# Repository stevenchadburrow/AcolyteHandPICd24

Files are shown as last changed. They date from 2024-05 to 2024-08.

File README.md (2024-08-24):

<b>Acolyte Hand PIC'd 24</b>

This is a single-chip retro-style computer using only the PIC24EP512GP204 microcontroller.  Inspired by Voja Antonic's design found here:  http://www.voja.rs/PROJECTS/GAME_HTM/1_intro.htm

It is designed to output VGA display at 320x240 with 16 colors, and 2-voice audio square waves.

It is designed to receive input from a Sega Genesis controller, PS/2 Keyboard or Mouse, and 8 on-board buttons.

It is designed to use a MicroSD Card Adapter, and an FT232RL USB Adapter.

Programmed using MPLAB IDE X via a PICkit3.

See my Youtube video for the Bad Apple demo. Either <a href="https://www.youtube.com/watch?v=rc4UsAqcSHg">without audio</a> or <a href="https://youtu.be/sSq6TWw3NXU">with audio</a>.

Also see my 'Pokemon Clone', video link <a href="https://youtu.be/8EHRpKk9gPc">here</a>.  Although I am using the Tuxemon game art assets, this project is not the Tuxemon game, nor are the creators of the Tuxemon game in charge of this project.  This project was simply inspired by the Tuxemon game.

Needed Changes:

*** LED silkscreen is confusing!!! ***

*** ICSP pins physically block the SDcard and FT232RL adapters!!! ***

*** Connected an MCP2221 to the USB connector for serial data transfer!!! ***

*** Tested with LCD, speaker, and with additional PIC24 chip for USB capability!!! ***

Updates:

Been working with the PIC24FJ128GB202 for USB capability.  Using the MLA projects from Microchip, I was able to combine USB Host capabilities for using Keyboad, Mouse, and Mass Storage Device.  See my .ZIP file for the entire project and all associated code.  It is connected to this main board through an RX/TX UART pair, currently at 9600 baud.  

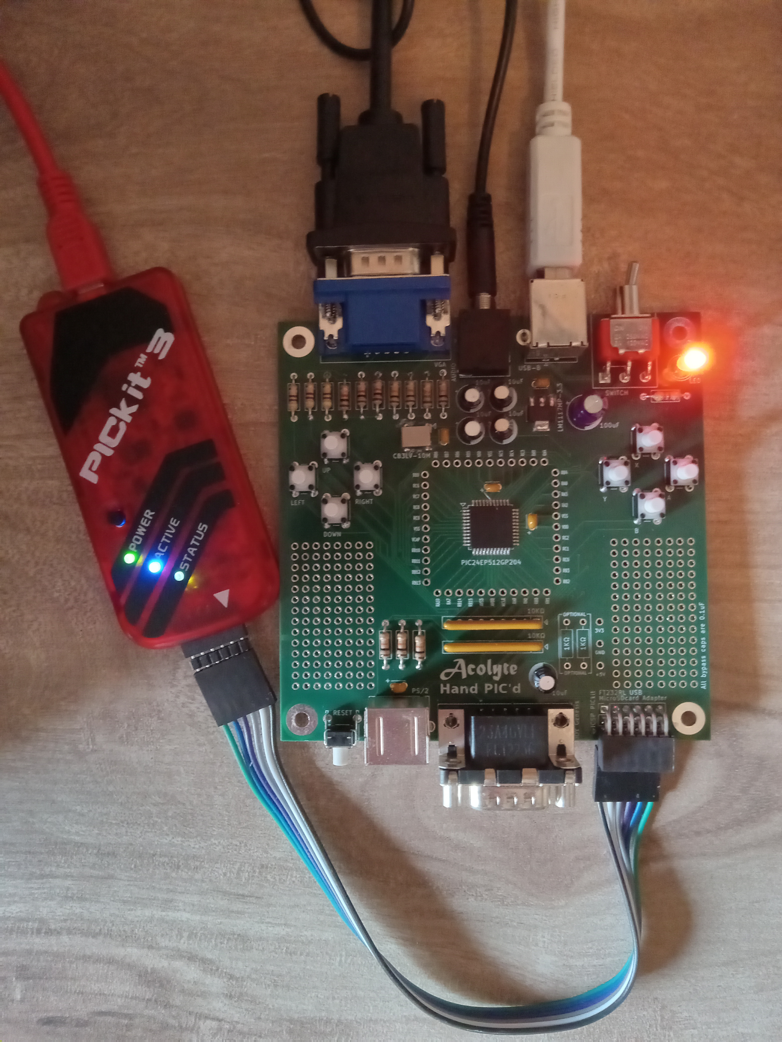
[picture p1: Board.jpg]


A full 16-colors are available!



Tetra always seems to be the first game for any system.

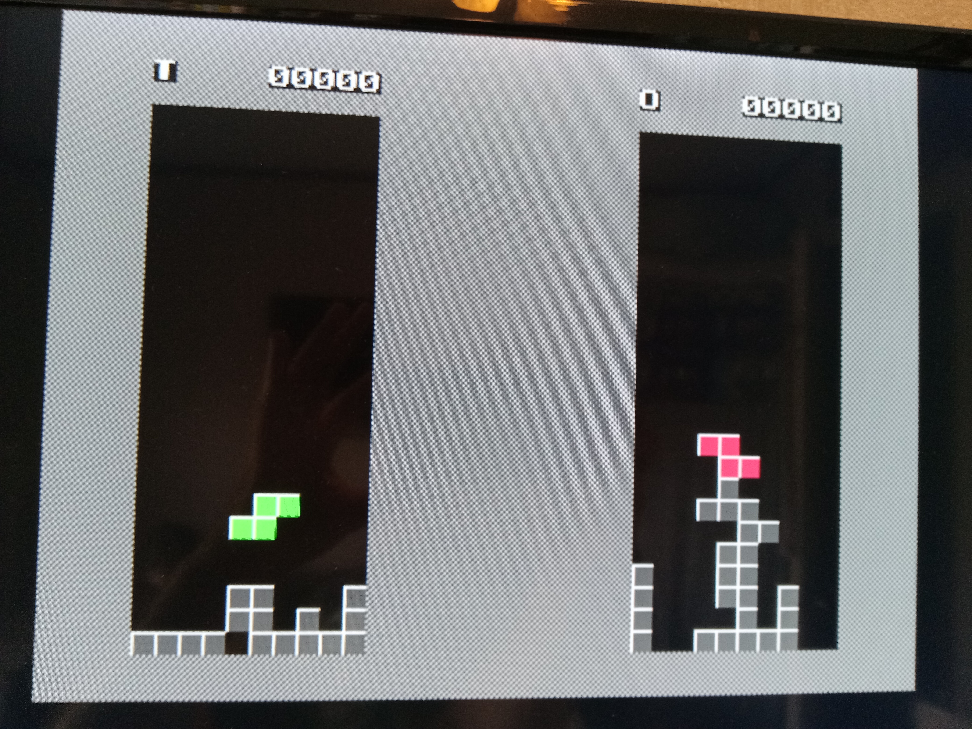
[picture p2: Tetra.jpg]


It can even run Bad Apple!

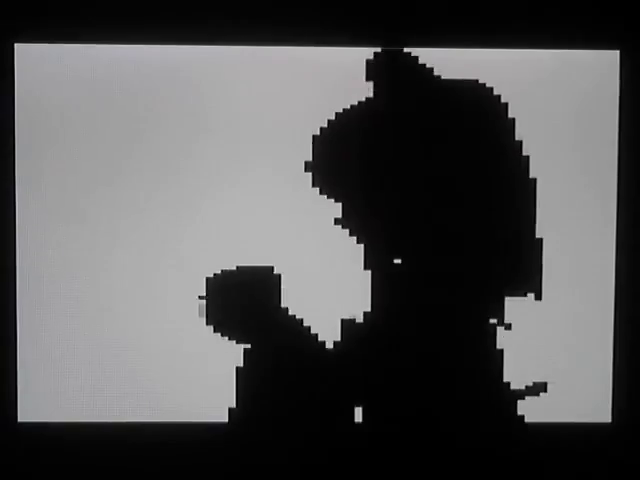
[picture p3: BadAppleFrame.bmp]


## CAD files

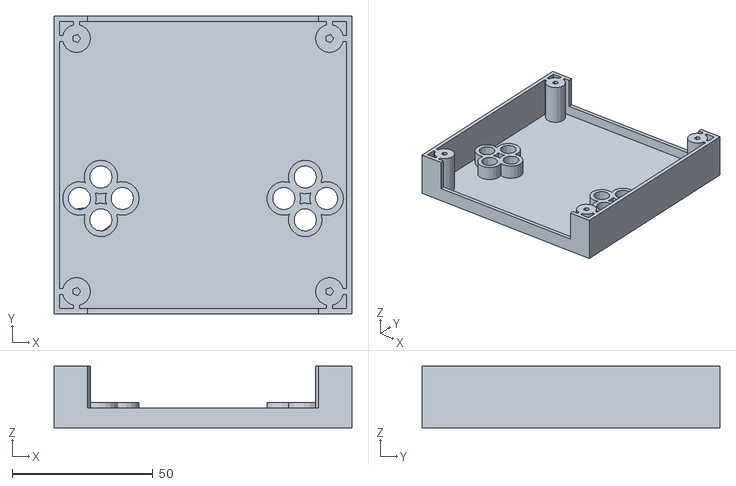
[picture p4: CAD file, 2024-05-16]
HandPICd24-BoxTop.stl
106.0 x 106.0 x 22.0

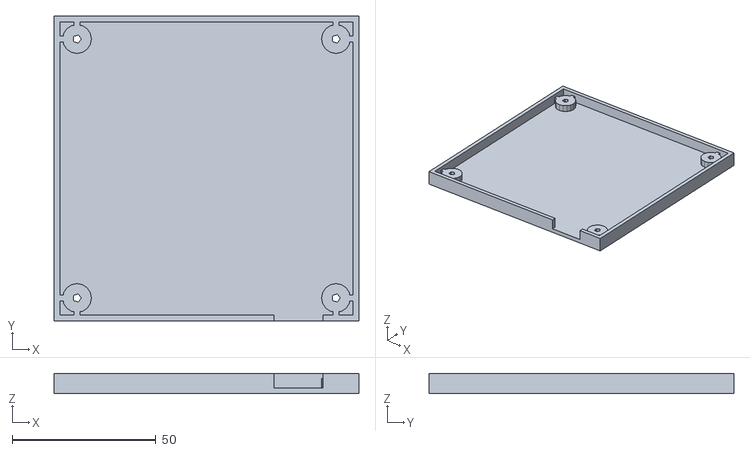
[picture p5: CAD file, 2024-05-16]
HandPICd24-BoxBottom.stl
106.0 x 106.0 x 7.00

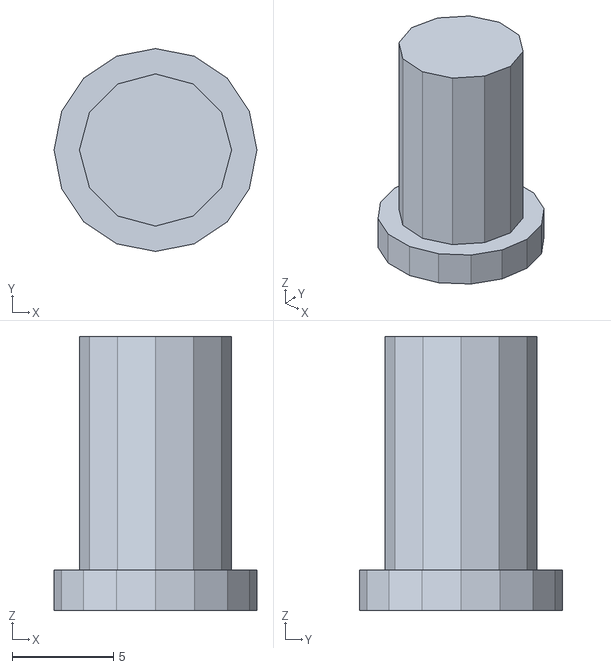
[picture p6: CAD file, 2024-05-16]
HandPICd24-BoxButton.stl
10.0 x 10.0 x 13.5

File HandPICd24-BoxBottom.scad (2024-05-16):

// bottom
translate([-3, -3, -2]) {
    difference() {
        cube([106, 106, 2], center = false);
        translate([3+5, 3+5, -1]) {
            cylinder(4, 3, 3);
        }
        translate([3+95, 3+5, -1]) {
            cylinder(4, 3, 3);
        }
        translate([3+95, 3+95, -1]) {
            cylinder(4, 3, 3);
        }
        translate([3+5, 3+95, -1]) {
            cylinder(4, 3, 3);
        }
    }
}

// front
translate([-3, -3, 0]) {
    difference() {
        cube([106, 2, 5], center = false);
        translate([73.5+3, -0.5, 0]) {
            cube([17, 3, 6], center = false);
        }
    }
}

// back
translate([-3, 101, 0]) {
    cube([106, 2, 5], center = false);
}

// left
translate([-3, -3, 0]) {
    cube([2, 106, 5], center = false);
}

// right
translate([101, -3, 0]) {
    cube([2, 106, 5], center = false);
}

// front left corner
translate([5, 5, 0]) {
    difference() {
        cylinder(3.25, 5, 5);
        translate([0, 0, -1]) {
            cylinder(4.5, 1.5, 1.5);
        }
    }
}
translate([4, -1, 0]) {
    cube([2, 3, 3.25], center = false);
}
translate([-1, 4, 0]) {
    cube([3, 2, 3.25], center = false);
}

// front right corner
translate([95, 5, 0]) {
    difference() {
        cylinder(3.25, 5, 5);
        translate([0, 0, -1]) {
            cylinder(4.5, 1.5, 1.5);
        }
    }
}
translate([94, -1, 0]) {
    cube([2, 3, 3.25], center = false);
}
translate([99, 4, 0]) {
    cube([3, 2, 3.25], center = false);
}

// back right corner
translate([95, 95, 0]) {
    difference() {
        cylinder(3.25, 5, 5);
        translate([0, 0, -1]) {
            cylinder(4.5, 1.5, 1.5);
        }
    }
}
translate([94, 99, 0]) {
    cube([2, 3, 3.25], center = false);
}
translate([99, 94, 0]) {
    cube([3, 2, 3.25], center = false);
}

// back left corner
translate([5, 95, 0]) {
    difference() {
        cylinder(3.25, 5, 5);
        translate([0, 0, -1]) {
            cylinder(4.5, 1.5, 1.5);
        }
    }
}
translate([4, 99, 0]) {
    cube([2, 3, 3.25], center = false);
}
translate([-1, 94, 0]) {
    cube([3, 2, 3.25], center = false);
}


/*
// CSG.scad - Basic example of CSG usage

translate([-24,0,0]) {
    union() {
        cube(15, center=true);
        sphere(10);
    }
}

intersection() {
    cube(15, center=true);
    sphere(10);
}

translate([24,0,0]) {
    difference() {
        cube(15, center=true);
        sphere(10);
    }
}

echo(version=version());
// Written by Marius Kintel <marius@kintel.net>
//
// To the extent possible under law, the author(s) have dedicated all
// copyright and related and neighboring rights to this software to the
// public domain worldwide. This software is distributed without any
// warranty.
//
// You should have received a copy of the CC0 Public Domain
// Dedication along with this software.
// If not, see <http://creativecommons.org/publicdomain/zero/1.0/>.
*/

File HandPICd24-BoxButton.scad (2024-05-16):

difference() {
    cylinder(2, 5, 5);
    cylinder(9, 1.5, 1.5);
}
translate([0, 0, 2]) {
    difference() {
        cylinder(7+2+2.5, 3.75, 3.75);
        cylinder(9, 1.5, 1.5);
    }
}

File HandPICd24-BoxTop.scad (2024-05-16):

// top
translate([-3, -3, -2]) {
    difference() {
        cube([106, 106, 2], center = false);
        
        translate([3, 3, 0]) {
            translate([6.06, 38.1, -1]) {
                cylinder(4, 4, 4);
            }
            translate([13.68, 45.72, -1]) {
                cylinder(4, 4, 4);
            }
            translate([21.3, 38.1, -1]) {
                cylinder(4, 4, 4);
            }
            translate([13.68, 30.48, -1]) {
                cylinder(4, 4, 4);
            }
            
            translate([6.06+72.68, 38.1, -1]) {
                cylinder(4, 4, 4);
            }
            translate([13.68+72.68, 45.72, -1]) {
                cylinder(4, 4, 4);
            }
            translate([21.3+72.68, 38.1, -1]) {
                cylinder(4, 4, 4);
            }
            translate([13.68+72.68, 30.48, -1]) {
                cylinder(4, 4, 4);
            }
        }
    }
}

// buttons
translate([6.06, 38.1, 0]) {
    difference() {
        cylinder(7, 6, 6);
        cylinder(7, 4, 4);
    }
/*
// testing buttons
translate([0, 0, 7]) {
rotate([180, 0, 0]) {
translate([0, 0, -2]) {
// insert button here
difference() {
    cylinder(2, 5, 5);
    cylinder(9, 1.5, 1.5);
}
translate([0, 0, 2]) {
    difference() {
        cylinder(7+2+2.5, 3.75, 3.75);
        cylinder(9, 1.5, 1.5);
    }
}
// end of button
}}}
*/
}
translate([13.68, 45.72, 0]) {
    difference() {
        cylinder(7, 6, 6);
        cylinder(7, 4, 4);
    }
/*    
// testing buttons
translate([0, 0, 7]) {
rotate([180, 0, 0]) {
translate([0, 0, -2]) {
// insert button here
difference() {
    cylinder(2, 5, 5);
    cylinder(9, 1.5, 1.5);
}
translate([0, 0, 2]) {
    difference() {
        cylinder(7+2+2.5, 3.75, 3.75);
        cylinder(9, 1.5, 1.5);
    }
}
// end of button
}}}
*/
}
translate([21.3, 38.1, 0]) {
    difference() {
        cylinder(7, 6, 6);
        cylinder(7, 4, 4);
    }
/*   
// testing buttons
translate([0, 0, 7]) {
rotate([180, 0, 0]) {
translate([0, 0, -2]) {
// insert button here
difference() {
    cylinder(2, 5, 5);
    cylinder(9, 1.5, 1.5);
}
translate([0, 0, 2]) {
    difference() {
        cylinder(7+2+2.5, 3.75, 3.75);
        cylinder(9, 1.5, 1.5);
    }
}
// end of button
}}}
*/    
}
translate([13.68, 30.48, 0]) {
    difference() {
        cylinder(7, 6, 6);
        cylinder(7, 4, 4);
    }
/*    
// testing buttons
translate([0, 0, 7]) {
rotate([180, 0, 0]) {
translate([0, 0, -2]) {
// insert button here
difference() {
    cylinder(2, 5, 5);
    cylinder(9, 1.5, 1.5);
}
translate([0, 0, 2]) {
    difference() {
        cylinder(7+2+2.5, 3.75, 3.75);
        cylinder(9, 1.5, 1.5);
    }
}
// end of button
}}}
*/
}

translate([6.06+72.68, 38.1, 0]) {
    difference() {
        cylinder(7, 6, 6);
        cylinder(7, 4, 4);
    }
}
translate([13.68+72.68, 45.72, 0]) {
    difference() {
        cylinder(7, 6, 6);
        cylinder(7, 4, 4);
    }
}
translate([21.3+72.68, 38.1, 0]) {
    difference() {
        cylinder(7, 6, 6);
        cylinder(7, 4, 4);
    }
}
translate([13.68+72.68, 30.48, 0]) {
    difference() {
        cylinder(7, 6, 6);
        cylinder(7, 4, 4);
    }
}

// back
translate([-3, -3, 0]) {
    difference() {
        cube([106, 2, 20], center = false);
        translate([3+9, -1, 5]) {
            cube([82, 4, 16], center = false);
        }
    }
}

// front
translate([-3, 101, 0]) {
    difference() {
        cube([106, 2, 20], center = false);
        translate([3+9, -1, 5]) {
            cube([82, 4, 16], center = false);
        }
    }
}

// right
translate([-3, -3, 0]) {
    cube([2, 106, 20], center = false);
}

// left
translate([101, -3, 0]) {
    cube([2, 106, 20], center = false);
}

// corner
translate([5, 5, 0]) {
    difference() {
        cylinder(20, 5, 5);
        translate([0, 0, -1]) {
            cylinder(21.25, 1.5, 1.5);
        }
    }
}
translate([4, -1, 0]) {
    cube([2, 3, 20], center = false);
}
translate([-1, 4, 0]) {
    cube([3, 2, 20], center = false);
}

// corner
translate([95, 5, 0]) {
    difference() {
        cylinder(20, 5, 5);
        translate([0, 0, -1]) {
            cylinder(21.25, 1.5, 1.5);
        }
    }
}
translate([94, -1, 0]) {
    cube([2, 3, 20], center = false);
}
translate([99, 4, 0]) {
    cube([3, 2, 20], center = false);
}

// corner
translate([95, 95, 0]) {
    difference() {
        cylinder(20, 5, 5);
        translate([0, 0, -1]) {
            cylinder(21.25, 1.5, 1.5);
        }
    }
}
translate([94, 99, 0]) {
    cube([2, 3, 20], center = false);
}
translate([99, 94, 0]) {
    cube([3, 2, 20], center = false);
}

// corner
translate([5, 95, 0]) {
    difference() {
        cylinder(20, 5, 5);
        translate([0, 0, -1]) {
            cylinder(21.25, 1.5, 1.5);
        }
    }
}
translate([4, 99, 0]) {
    cube([2, 3, 20], center = false);
}
translate([-1, 94, 0]) {
    cube([3, 2, 20], center = false);
}


/*
// CSG.scad - Basic example of CSG usage

translate([-24,0,0]) {
    union() {
        cube(15, center=true);
        sphere(10);
    }
}

intersection() {
    cube(15, center=true);
    sphere(10);
}

translate([24,0,0]) {
    difference() {
        cube(15, center=true);
        sphere(10);
    }
}

echo(version=version());
// Written by Marius Kintel <marius@kintel.net>
//
// To the extent possible under law, the author(s) have dedicated all
// copyright and related and neighboring rights to this software to the
// public domain worldwide. This software is distributed without any
// warranty.
//
// You should have received a copy of the CC0 Public Domain
// Dedication along with this software.
// If not, see <http://creativecommons.org/publicdomain/zero/1.0/>.
*/

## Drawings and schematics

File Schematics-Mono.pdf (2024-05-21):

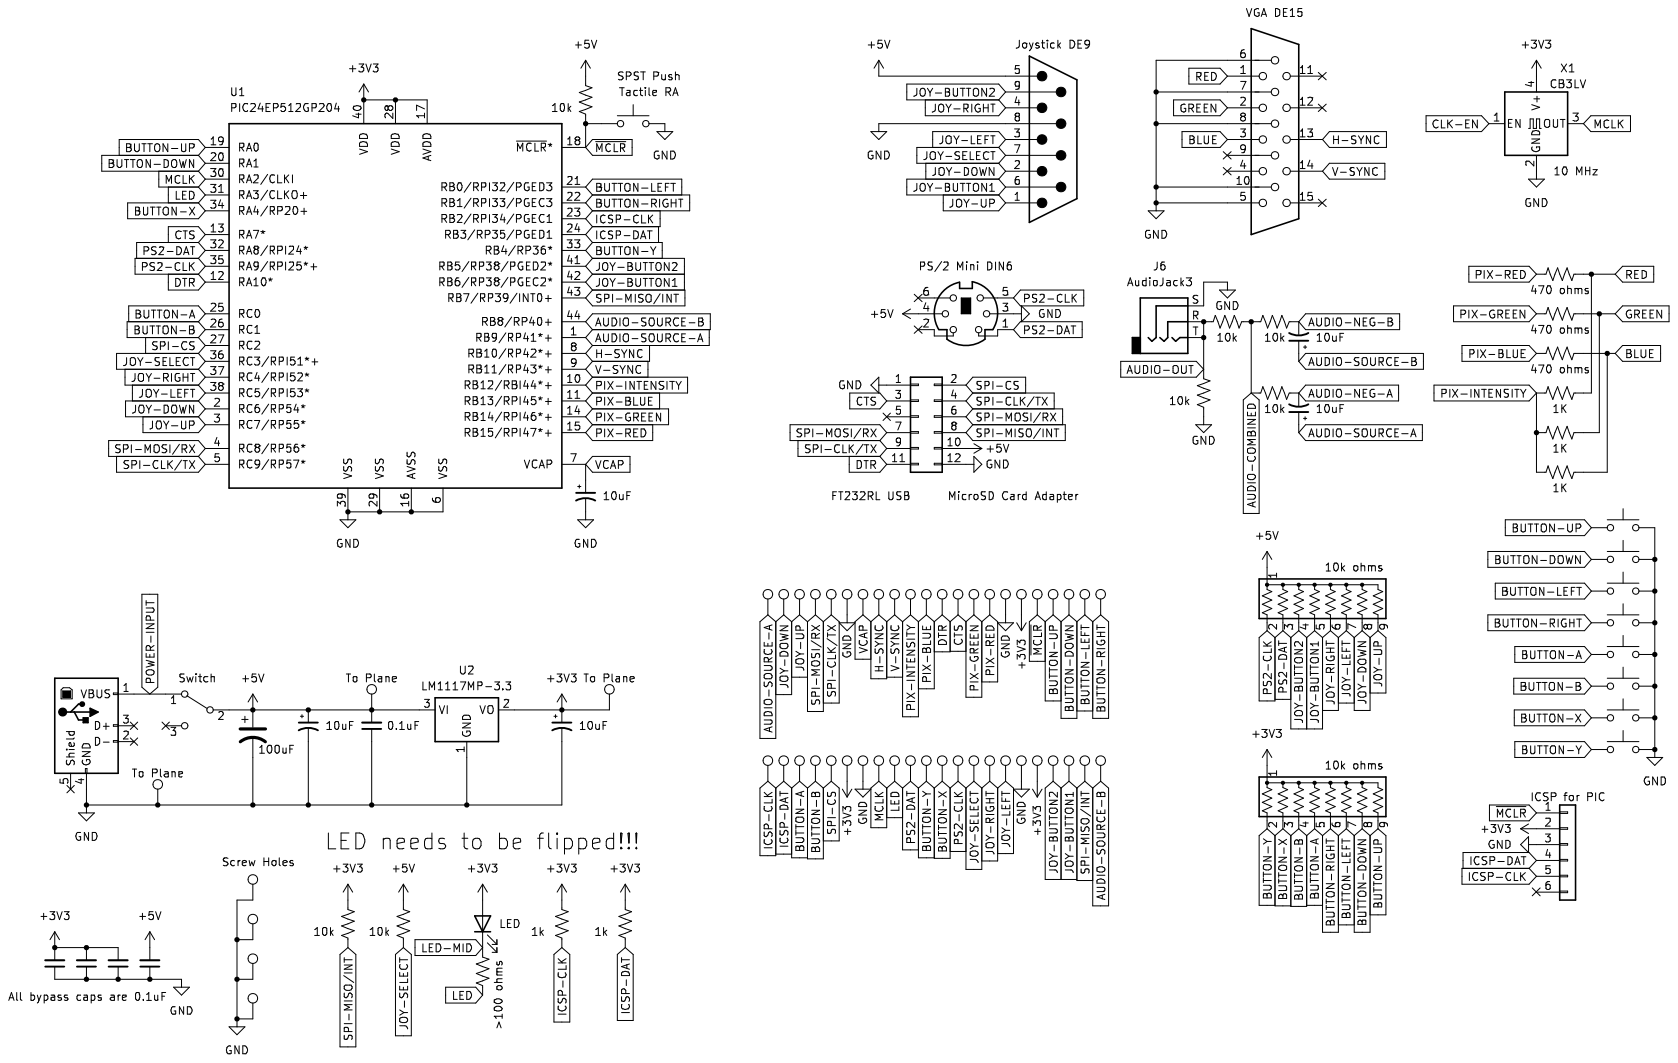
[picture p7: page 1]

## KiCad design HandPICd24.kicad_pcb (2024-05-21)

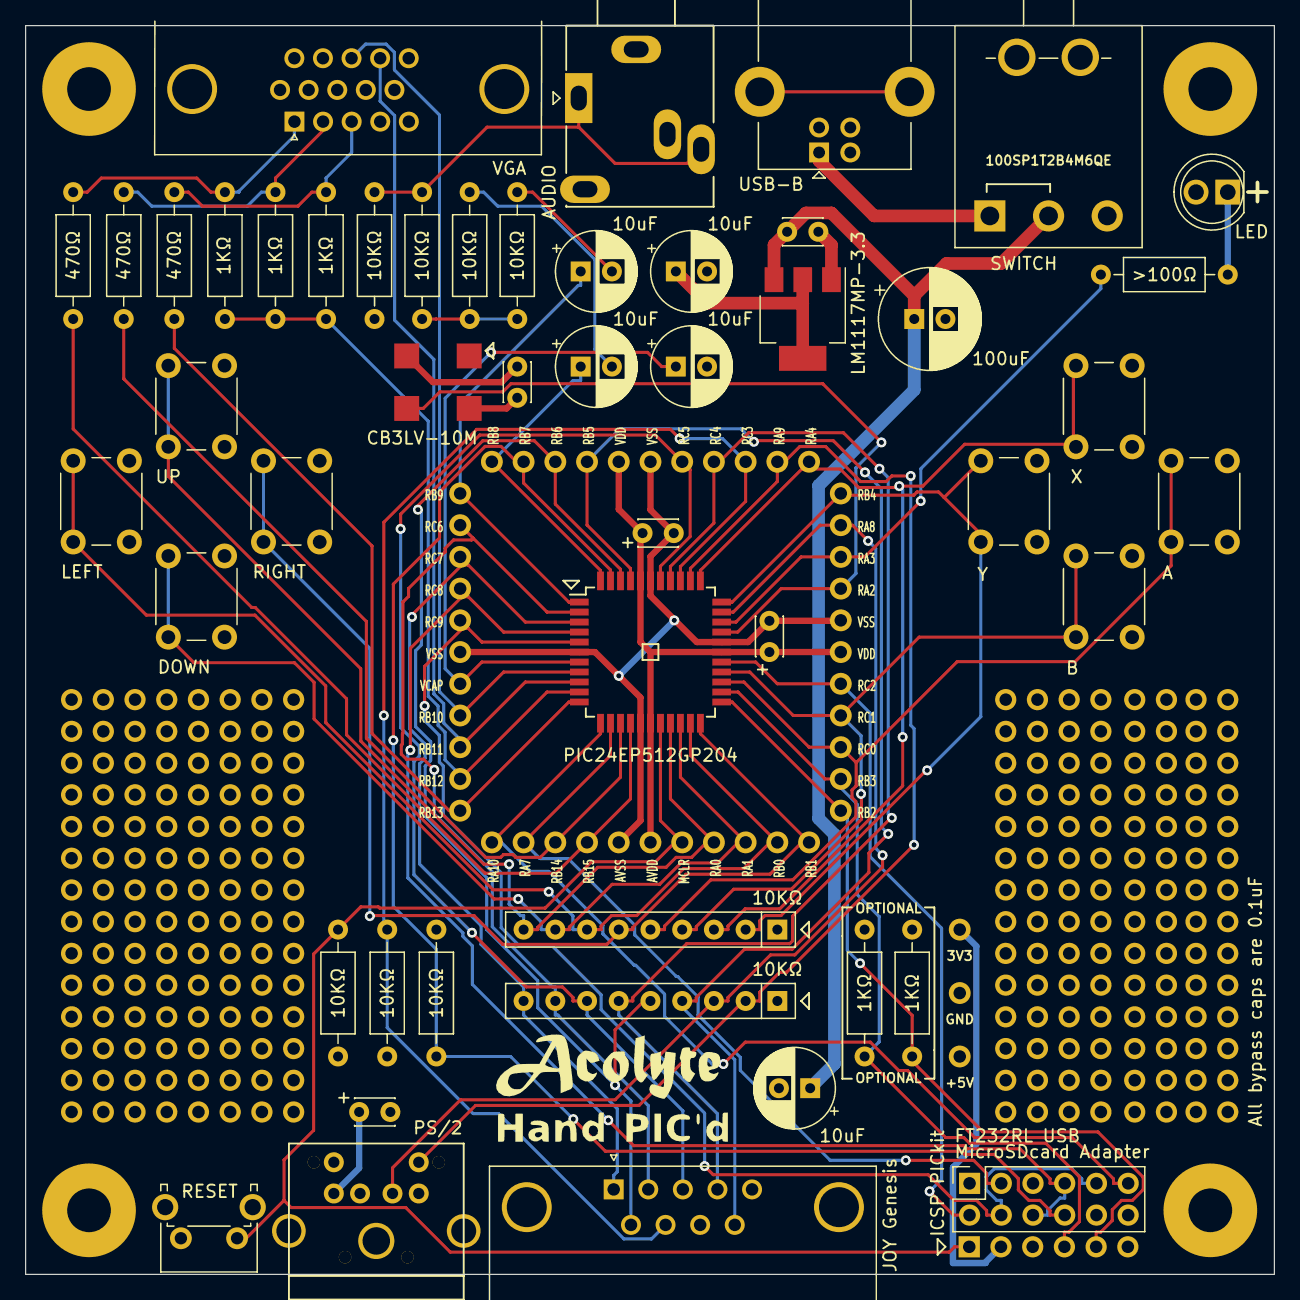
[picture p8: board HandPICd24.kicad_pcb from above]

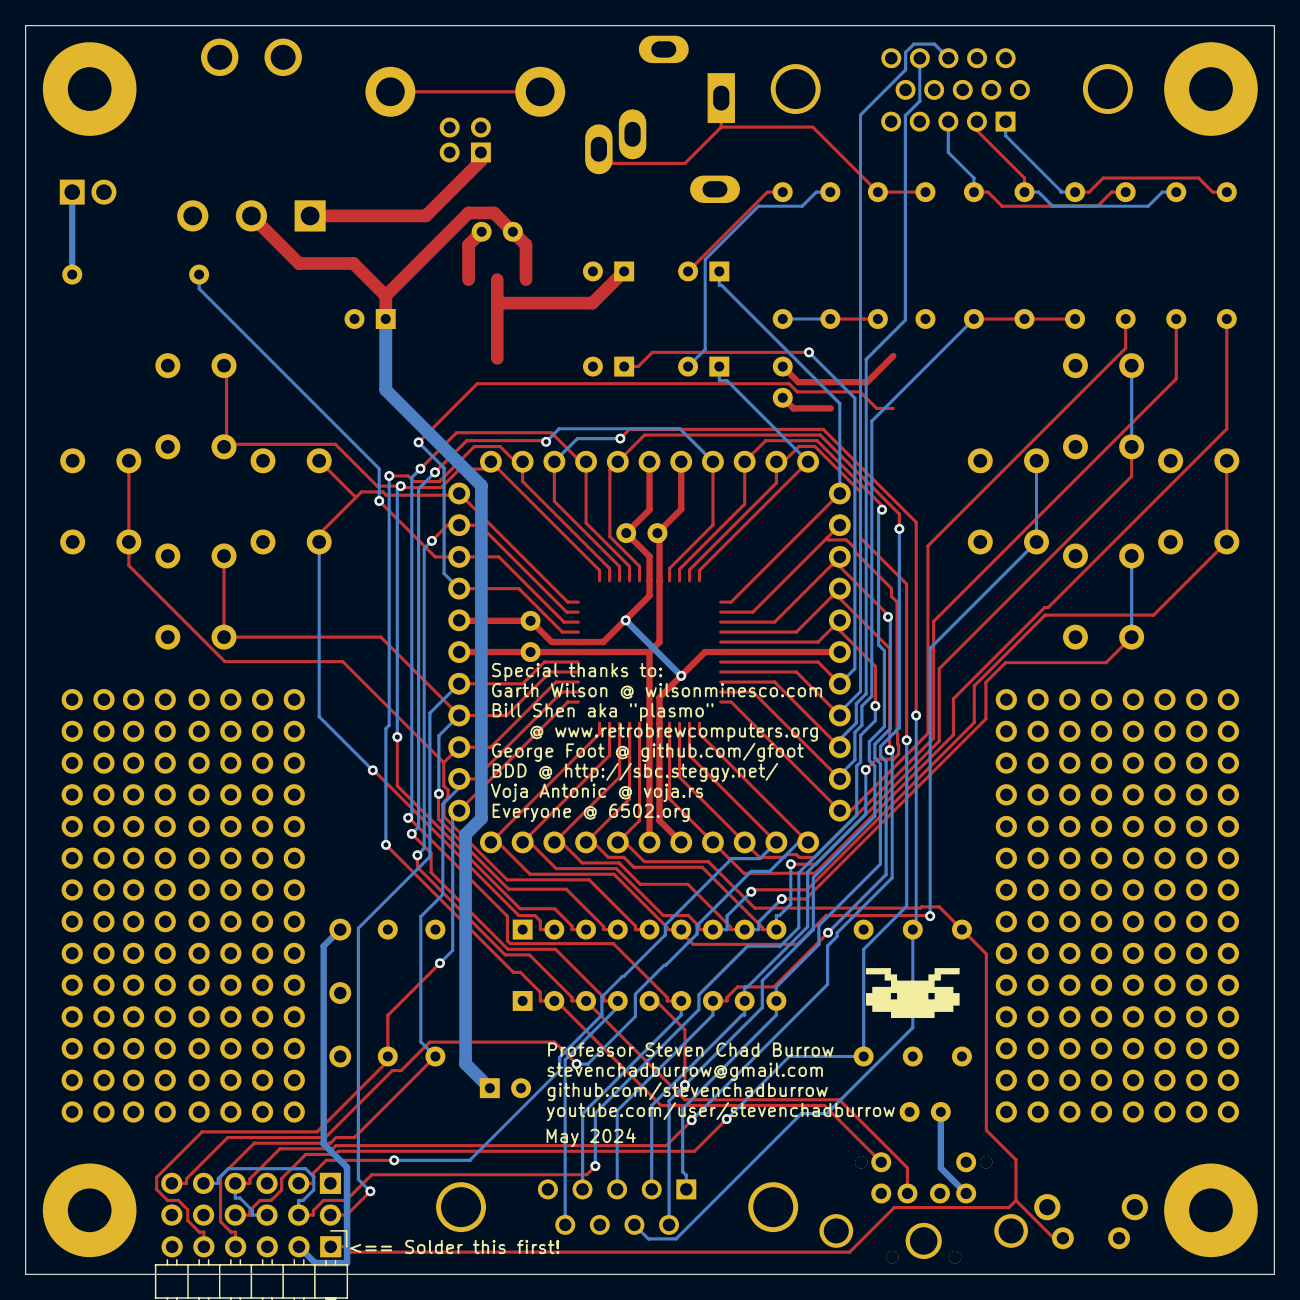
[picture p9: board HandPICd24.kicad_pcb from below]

Board: 4 copper layers, 100.0 x 100.0 mm, 112 parts (2 on the bottom side), 49 nets.

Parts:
C1, C3, C4, C6, C8: C_Polarized_Small_US; CP_Radial_D6.3mm_P2.50mm
C2: C_Polarized_US; CP_Radial_D8.0mm_P2.50mm
C5, C7, C19, C25, C28: C_Small; C_Disc_D3.0mm_W2.0mm_P2.50mm
D1: LED; CustomLED
G101: LOGO; AcolyteTitle
G102: LOGO; HandPickedTitle
G103: LOGO; Mystery
J1: Conn_02x06_Odd_Even; PinSocket_2x06_P2.54mm_Vertical
J2: Mini-DIN-6; PS2_Din6
J3: DE9_Plug; DSUB-9_Male_Horizontal_P2.77x2.84mm_EdgePinOffset7.70mm_Hou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
J4: USB_B; USB_B_Lumberg_2411_02_Horizontal
J5: DE15_Receptacle_HighDensity; DSUB-15-HD_Female_Horizontal_P2.29x2.54mm_VGA
J6: AudioJack3; BIGJack_3.5mm_Ledino_KB3SPRS_Horizontal
J10, J11, J12, J13, J14, J15, J16, J17: Conn_02x14_Odd_Even; BLANK-PinHeader_2x14_P2.54mm_Vertical
J18: Conn_01x06; PinHeader_1x06_P2.54mm_Horizontal
R1, R2, R3, R4, R5, R6, R7, R8, R9, R10, R11, R12, R13, R14, R15, R17: R_US; R_Axial_DIN0207_L6.3mm_D2.5mm_P10.16mm_Horizontal
RN1, RN2: R_Network08_US; R_Array_SIP9
SW1: SW_Push; SW_Tactile_SPST_Angled_PTS645Vx83-2LFS
SW2, SW4, SW5, SW6, SW7, SW8, SW9, SW10: SW_Push; SW_PUSH_6mm_H5mm
SW3: SW_SPDT; SPDT-100SP1T2B4M6QE
TP1, TP2, TP3, TP4: TestPoint; ScrewHole-4-40
TP5, TP6, TP7, TP8, TP9, TP10, TP11, TP12, TP13, TP14, TP15, TP16, TP17, TP18, TP19, TP20, TP21, TP22, TP23, TP24, TP25, TP26, TP27, TP28, TP29, TP30, TP31, TP32, TP33, TP34, TP35, TP36, TP37, TP38, TP39, TP40, TP41, TP42, TP43, TP44, TP45, TP46, TP47, TP48, TP49, TP50, TP53: TestPoint; TestPointStdTHT
U1: PIC24EP512GP204; TQFP-44_10x10mm_P0.8mm
U2: LM1117MP-3.3; SOT-223-3_TabPin2
X1: CB3LV; Oscillator_SMD_EuroQuartz_XO91-4Pin_7.0x5.0mm

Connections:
+3V3: C6.1, C19.2, C25.2, C28.2, D1.2 (A), J18.2, R4.2, R7.2, R15.2, RN2.1 (common), TP21.1, TP32.1, TP44.1, TP53.1, U1.17 (AVDD), U1.28 (VDD), U1.40 (VDD), U2.2 (VO), X1.4 (V+)
+5V: C2.1, C5.2, C7.2, C8.1, J1.10, J2.4, J3.5, R1.2, R17.2, RN1.1 (common), SW3.2 (B), TP50.1, U2.3 (VI)
AUDIO-COMBINED: R3.2, R5.1, R6.1
AUDIO-NEG-A: C4.2, R6.2
AUDIO-NEG-B: C3.2, R5.2
AUDIO-OUT: J6.R, J6.T, R2.2, R3.1
AUDIO-SOURCE-A: C4.1, TP5.1, U1.1 (RB9/RP41*+)
AUDIO-SOURCE-B: C3.1, TP48.1, U1.44 (RB8/RP40+)
BLUE: J5.3, R10.2, R13.2
BUTTON-A: RN2.5 (R4), SW7.1, TP29.1, U1.25 (RC0)
BUTTON-B: RN2.4 (R3), SW8.1, TP30.1, U1.26 (RC1)
BUTTON-DOWN: RN2.8 (R7), SW4.1, TP24.1, U1.20 (RA1)
BUTTON-LEFT: RN2.7 (R6), SW5.1, TP25.1, U1.21 (RB0/RPI32/PGED3)
BUTTON-RIGHT: RN2.6 (R5), SW6.1, TP26.1, U1.22 (RB1/RPI33/PGEC3)
BUTTON-UP: RN2.9 (R8), SW2.1, TP23.1, U1.19 (RA0)
BUTTON-X: RN2.3 (R2), SW9.1, TP38.1, U1.34 (RA4/RP20+)
BUTTON-Y: RN2.2 (R1), SW10.1, TP37.1, U1.33 (RB4/RP36*)
CTS: J1.3, TP17.1, U1.13 (RA7*)
DTR: J1.11, TP16.1, U1.12 (RA10*)
GND: C1.2, C2.2, C5.1, C6.2, C7.1, C8.2, C19.1, C25.1, C28.1, J1.1, J1.12, J2.3, J3.8, J4.4 (GND), J5.5, J5.6, J5.7, J5.8, J5.10, J6.S, J18.3, R2.1, SW1.2, SW2.2, SW4.2, SW5.2, SW6.2, SW7.2, SW8.2, SW9.2, SW10.2, TP1.1, TP2.1, TP3.1, TP4.1, TP10.1, TP20.1, TP33.1, TP43.1, TP49.1, U1.6 (VSS), U1.16 (AVSS), U1.29 (VSS), U1.39 (VSS), U2.1 (GND), X1.2 (GND)
GREEN: J5.2, R9.2, R12.2
H-SYNC: J5.13, TP12.1, U1.8 (RB10/RP42*+)
ICSP-CLK: J18.5, R4.1, TP27.1, U1.23 (RB2/RPI34/PGEC1)
ICSP-DAT: J18.4, R15.1, TP28.1, U1.24 (RB3/RP35/PGED1)
JOY-BUTTON1: J3.6, RN1.5 (R4), TP46.1, U1.42 (RB6/RP38/PGEC2*)
JOY-BUTTON2: J3.9, RN1.4 (R3), TP45.1, U1.41 (RB5/RP38/PGED2*)
JOY-DOWN: J3.2, RN1.8 (R7), TP6.1, U1.2 (RC6/RP54*)
JOY-LEFT: J3.3, RN1.7 (R6), TP42.1, U1.38 (RC5/RPI53*)
JOY-RIGHT: J3.4, RN1.6 (R5), TP41.1, U1.37 (RC4/RPI52*)
JOY-SELECT: J3.7, R17.1, TP40.1, U1.36 (RC3/RPI51*+)
JOY-UP: J3.1, RN1.9 (R8), TP7.1, U1.3 (RC7/RP55*)
LED: R14.2, TP35.1, U1.31 (RA3/CLKO+)
LED-MID: D1.1 (K), R14.1
MCLK: TP34.1, U1.30 (RA2/CLKI), X1.3 (OUT)
PIX-BLUE: R10.1, TP15.1, U1.11 (RB13/RPI45*+)
PIX-GREEN: R9.1, TP18.1, U1.14 (RB14/RPI46*+)
PIX-INTENSITY: R11.1, R12.1, R13.1, TP14.1, U1.10 (RB12/RBI44*+)
PIX-RED: R8.1, TP19.1, U1.15 (RB15/RPI47*+)
POWER-INPUT: J4.1 (VBUS), SW3.1 (A)
PS2-CLK: J2.5, RN1.2 (R1), TP39.1, U1.35 (RA9/RPI25*+)
PS2-DAT: J2.1, RN1.3 (R2), TP36.1, U1.32 (RA8/RPI24*)
RED: J5.1, R8.2, R11.2
SPI-CLK/TX: J1.4, J1.9, TP9.1, U1.5 (RC9/RP57*)
SPI-CS: J1.2, TP31.1, U1.27 (RC2)
SPI-MISO/INT: J1.8, R7.1, TP47.1, U1.43 (RB7/RP39/INT0+)
SPI-MOSI/RX: J1.6, J1.7, TP8.1, U1.4 (RC8/RP56*)
V-SYNC: J5.14, TP13.1, U1.9 (RB11/RP43*+)
VCAP: C1.1, TP11.1, U1.7 (VCAP)
~MCLR: J18.1, R1.1, SW1.1, TP22.1, U1.18 (~MCLR*)

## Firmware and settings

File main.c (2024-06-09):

/******************************************************************************/
/* Files to Include                                                           */
/******************************************************************************/

/* Device header file */
#if defined(__XC16__)
    #include <xc.h>
#elif defined(__C30__)
    #if defined(__PIC24E__)
    	#include <p24Exxxx.h>
    #elif defined (__PIC24F__)||defined (__PIC24FK__)
	#include <p24Fxxxx.h>
    #elif defined(__PIC24H__)
	#include <p24Hxxxx.h>
    #endif
#endif

#include <stdint.h>        /* Includes uint16_t definition                    */
#include <stdbool.h>       /* Includes true/false definition                  */

/* Microcontroller MIPs (FCY) */
#define SYS_FREQ        10000000L
#define FCY             SYS_FREQ/2


/*
// PIC24EP512GP204 Configuration Bit Settings

// 'C' source line config statements

// FICD
#pragma config ICS = PGD1               // ICD Communication Channel Select bits (Communicate on PGEC1 and PGED1)
#pragma config JTAGEN = OFF             // JTAG Enable bit (JTAG is disabled)

// FPOR
#pragma config ALTI2C1 = OFF            // Alternate I2C1 pins (I2C1 mapped to SDA1/SCL1 pins)
#pragma config ALTI2C2 = OFF            // Alternate I2C2 pins (I2C2 mapped to SDA2/SCL2 pins)
#pragma config WDTWIN = WIN25           // Watchdog Window Select bits (WDT Window is 25% of WDT period)

// FWDT
#pragma config WDTPOST = PS32768        // Watchdog Timer Postscaler bits (1:32,768)
#pragma config WDTPRE = PR128           // Watchdog Timer Prescaler bit (1:128)
#pragma config PLLKEN = ON              // PLL Lock Enable bit (Clock switch to PLL source will wait until the PLL lock signal is valid.)
#pragma config WINDIS = OFF             // Watchdog Timer Window Enable bit (Watchdog Timer in Non-Window mode)
#pragma config FWDTEN = OFF             // Watchdog Timer Enable bit (Watchdog timer enabled/disabled by user software)

// FOSC
#pragma config POSCMD = EC              // Primary Oscillator Mode Select bits (EC (External Clock) Mode)
#pragma config OSCIOFNC = ON            // OSC2 Pin Function bit (OSC2 is general purpose digital I/O pin)
#pragma config IOL1WAY = OFF            // Peripheral pin select configuration (Allow multiple reconfigurations)
#pragma config FCKSM = CSECMD           // Clock Switching Mode bits (Clock switching is enabled,Fail-safe Clock Monitor is disabled)

// FOSCSEL
#pragma config FNOSC = FRC              // Oscillator Source Selection (Internal Fast RC (FRC))
#pragma config IESO = OFF               // Two-speed Oscillator Start-up Enable bit (Start up with user-selected oscillator source)

// FGS
#pragma config GWRP = OFF               // General Segment Write-Protect bit (General Segment may be written)
#pragma config GCP = OFF                // General Segment Code-Protect bit (General Segment Code protect is Disabled)

// #pragma config statements should precede project file includes.
// Use project enums instead of #define for ON and OFF.

#include <xc.h>
*/



// PIC24EP512GP204 Configuration Bit Settings

// 'C' source line config statements

// FICD
#pragma config ICS = PGD1               // ICD Communication Channel Select bits (Communicate on PGEC1 and PGED1)
#pragma config JTAGEN = OFF             // JTAG Enable bit (JTAG is disabled)

// FPOR
#pragma config ALTI2C1 = OFF            // Alternate I2C1 pins (I2C1 mapped to SDA1/SCL1 pins)
#pragma config ALTI2C2 = OFF            // Alternate I2C2 pins (I2C2 mapped to SDA2/SCL2 pins)
#pragma config WDTWIN = WIN25           // Watchdog Window Select bits (WDT Window is 25% of WDT period)

// FWDT
#pragma config WDTPOST = PS32768        // Watchdog Timer Postscaler bits (1:32,768)
#pragma config WDTPRE = PR128           // Watchdog Timer Prescaler bit (1:128)
#pragma config PLLKEN = ON              // PLL Lock Enable bit (Clock switch to PLL source will wait until the PLL lock signal is valid.)
#pragma config WINDIS = OFF             // Watchdog Timer Window Enable bit (Watchdog Timer in Non-Window mode)
#pragma config FWDTEN = OFF             // Watchdog Timer Enable bit (Watchdog timer enabled/disabled by user software)

// FOSC
#pragma config POSCMD = XT              // Primary Oscillator Mode Select bits (XT Crystal Oscillator Mode)
#pragma config OSCIOFNC = OFF           // OSC2 Pin Function bit (OSC2 is clock output)
#pragma config IOL1WAY = OFF            // Peripheral pin select configuration (Allow multiple reconfigurations)
#pragma config FCKSM = CSECMD           // Clock Switching Mode bits (Clock switching is enabled,Fail-safe Clock Monitor is disabled)

// FOSCSEL
#pragma config FNOSC = PRIPLL           // Oscillator Source Selection (Primary Oscillator with PLL module (XT + PLL, HS + PLL, EC + PLL))
#pragma config IESO = ON                // Two-speed Oscillator Start-up Enable bit (Start up device with FRC, then switch to user-selected oscillator source)

// FGS
#pragma config GWRP = OFF               // General Segment Write-Protect bit (General Segment may be written)
#pragma config GCP = OFF                // General Segment Code-Protect bit (General Segment Code protect is Disabled)

// #pragma config statements should precede project file includes.
// Use project enums instead of #define for ON and OFF.

#include <xc.h>



/******************************************************************************/
/* Trap Function Prototypes                                                   */
/******************************************************************************/

/* <Other function prototypes for debugging trap code may be inserted here>   */

/* Use if INTCON2 ALTIVT=1 */
void __attribute__((interrupt,no_auto_psv)) _OscillatorFail(void);
void __attribute__((interrupt,no_auto_psv)) _AddressError(void);
void __attribute__((interrupt,no_auto_psv)) _StackError(void);
void __attribute__((interrupt,no_auto_psv)) _MathError(void);

#if defined(__PIC24F__)||defined(__PIC24H__)

/* Use if INTCON2 ALTIVT=0 */
void __attribute__((interrupt,no_auto_psv)) _AltOscillatorFail(void);
void __attribute__((interrupt,no_auto_psv)) _AltAddressError(void);
void __attribute__((interrupt,no_auto_psv)) _AltStackError(void);
void __attribute__((interrupt,no_auto_psv)) _AltMathError(void);

#endif

/* Default interrupt handler */
void __attribute__((interrupt,no_auto_psv)) _DefaultInterrupt(void);

#if defined(__PIC24E__)

/* These are additional traps in the 24E family.  Refer to the PIC24E
migration guide.  There are no Alternate Vectors in the 24E family. */
void __attribute__((interrupt,no_auto_psv)) _HardTrapError(void);
void __attribute__((interrupt,no_auto_psv)) _DMACError(void);
void __attribute__((interrupt,no_auto_psv)) _SoftTrapError(void);

#endif

/******************************************************************************/
/* Trap Handling                                                              */
/*                                                                            */
/* These trap routines simply ensure that the device continuously loops       */
/* within each routine.  Users who actually experience one of these traps     */
/* can add code to handle the error.  Some basic examples for trap code,      */
/* including assembly routines that process trap sources, are available at    */
/* www.microchip.com/codeexamples                                             */
/******************************************************************************/

/* Primary (non-alternate) address error trap function declarations */
void __attribute__((interrupt,no_auto_psv)) _OscillatorFail(void)
{
        INTCON1bits.OSCFAIL = 0;        /* Clear the trap flag */
        while(1);
}

void __attribute__((interrupt,no_auto_psv)) _AddressError(void)
{
        INTCON1bits.ADDRERR = 0;        /* Clear the trap flag */
        while (1);
}
void __attribute__((interrupt,no_auto_psv)) _StackError(void)
{
        INTCON1bits.STKERR = 0;         /* Clear the trap flag */
        while (1);
}

void __attribute__((interrupt,no_auto_psv)) _MathError(void)
{
        INTCON1bits.MATHERR = 0;        /* Clear the trap flag */
        while (1);
}

#if defined(__PIC24F__)||defined(__PIC24H__)

/* Alternate address error trap function declarations */
void __attribute__((interrupt,no_auto_psv)) _AltOscillatorFail(void)
{
        INTCON1bits.OSCFAIL = 0;        /* Clear the trap flag */
        while (1);
}

void __attribute__((interrupt,no_auto_psv)) _AltAddressError(void)
{
        INTCON1bits.ADDRERR = 0;        /* Clear the trap flag */
        while (1);
}

void __attribute__((interrupt,no_auto_psv)) _AltStackError(void)
{
        INTCON1bits.STKERR = 0;         /* Clear the trap flag */
        while (1);
}

void __attribute__((interrupt,no_auto_psv)) _AltMathError(void)
{
        INTCON1bits.MATHERR = 0;        /* Clear the trap flag */
        while (1);
}

#endif

/******************************************************************************/
/* Default Interrupt Handler                                                  */
/*                                                                            */
/* This executes when an interrupt occurs for an interrupt source with an     */
/* improperly defined or undefined interrupt handling routine.                */
/******************************************************************************/
void __attribute__((interrupt,no_auto_psv)) _DefaultInterrupt(void)
{
        while(1);
}

#if defined(__PIC24E__)

/* These traps are new to the PIC24E family.  Refer to the device Interrupt
chapter of the FRM to understand trap priority. */
void __attribute__((interrupt,no_auto_psv)) _HardTrapError(void)
{
    while(1);
}
void __attribute__((interrupt,no_auto_psv)) _DMACError(void)
{
    while(1);
}
void __attribute__((interrupt,no_auto_psv)) _SoftTrapError(void)
{
    while(1);
}

#endif

/******************************************************************************/
/* Main Program                                                               */
/******************************************************************************/


// only 80 used, but last 2 needed for other reasons
unsigned int line[96] __at(0x1000) = {
  0x0000, 0x0000, 0x0000, 0x0000,
  0x0000, 0x0000, 0x0000, 0x0000,
  0x0000, 0x0000, 0x0000, 0x0000,
  0x0000, 0x0000, 0x0000, 0x0000,
  
  0x0000, 0x0000, 0x0000, 0x0000,
  0x0000, 0x0000, 0x0000, 0x0000,
  0x0000, 0x0000, 0x0000, 0x0000,
  0x0000, 0x0000, 0x0000, 0x0000,
  
  0x0000, 0x0000, 0x0000, 0x0000,
  0x0000, 0x0000, 0x0000, 0x0000,
  0x0000, 0x0000, 0x0000, 0x0000,
  0x0000, 0x0000, 0x0000, 0x0000,
  
  0x0000, 0x0000, 0x0000, 0x0000,
  0x0000, 0x0000, 0x0000, 0x0000,
  0x0000, 0x0000, 0x0000, 0x0000,
  0x0000, 0x0000, 0x0000, 0x0000,
  
  0x0000, 0x0000, 0x0000, 0x0000,
  0x0000, 0x0000, 0x0000, 0x0000,
  0x0000, 0x0000, 0x0000, 0x0000,
  0x0000, 0x0000, 0x0000, 0x0000,
  
  0x0000, 0x0000, 0x0000, 0x0000,
  0x0000, 0x0000, 0x0000, 0x0000,
  0x0000, 0x0000, 0x0000, 0x0000,
  0x0000, 0x0000, 0x0000, 0x0000
};

// 80 * 240 * 2-byte word = 38400 bytes
// 80 words * 4 pixels per word = 320 pixels horizontal
// 240 pixels vertically
// result: 320x240 with 16 colors
unsigned int screen[80*240] __at(0x2000);

// interrupt latency is 10 cycles
// for some reason, having auto_psv instead of no_auto_psv makes this work?!
void __attribute__((__interrupt__, auto_psv, address(0x002000))) _T1Interrupt(void)
{
	// C always includes:
	// lnk #0
  
	drawScanline();
	
	// C always includes:
	// ulnk
	// retfie
};



const __prog__ unsigned int __attribute__((space(prog))) character_bitmap[1536] = 
//const unsigned int character_bitmap[1536] =
{
	0x0000,0x0000,0x0000,0x0000,0x0000,0x0000,0x0000,0x0000, // 32
	0x0000,0x0000,0x0000,0x0000,0x0000,0x0000,0x0000,0x0000,
	0x00FF,0x0000,0x0FFF,0xF000,0x0FFF,0xF000,0x0FFF,0xF000,
	0x00FF,0x0000,0x0000,0x0000,0x00FF,0x0000,0x0000,0x0000,
	0x00F0,0x0F00,0x0F00,0xF000,0x0FF0,0xFF00,0x0FF0,0xFF00,
	0x0000,0x0000,0x0000,0x0000,0x0000,0x0000,0x0000,0x0000,
	0x0FF0,0xFF00,0xFFFF,0xFFF0,0x0FF0,0xFF00,0x0FF0,0xFF00,
	0x0FF0,0xFF00,0xFFFF,0xFFF0,0x0FF0,0xFF00,0x0000,0x0000,
	0x000F,0x0000,0x0FFF,0xFFF0,0xFF0F,0x0000,0x0FFF,0xFF00,
	0x000F,0x0FF0,0xFFFF,0xFF00,0x000F,0x0000,0x0000,0x0000,
	0x0F00,0x00F0,0xF0F0,0x0FF0,0x0F00,0xFF00,0x000F,0xF000,
	0x00FF,0x0F00,0x0FF0,0xF0F0,0xFF00,0x0F00,0x0000,0x0000,
	0x0FFF,0x0000,0xFF0F,0xF000,0x0FFF,0x0000,0xFF0F,0xF0F0,
	0xFF00,0xFFF0,0xFF00,0x0FF0,0x0FFF,0xFF00,0x0000,0x0000,
	0x00FF,0x0000,0x00FF,0x0000,0x000F,0x0000,0x00F0,0x0000,
	0x0000,0x0000,0x0000,0x0000,0x0000,0x0000,0x0000,0x0000,
	0x000F,0xFF00,0x00FF,0x0000,0x0FF0,0x0000,0x0FF0,0x0000,
	0x0FF0,0x0000,0x00FF,0x0000,0x000F,0xFF00,0x0000,0x0000,
	0x0FFF,0x0000,0x000F,0xF000,0x0000,0xFF00,0x0000,0xFF00,
	0x0000,0xFF00,0x000F,0xF000,0x0FFF,0x0000,0x0000,0x0000,
	0x0000,0x0000,0x0000,0x0000,0x0FF0,0xFF00,0x00FF,0xF000,
	0x0FF0,0xFF00,0x0000,0x0000,0x0000,0x0000,0x0000,0x0000,
	0x0000,0x0000,0x0000,0x0000,0x000F,0x0000,0x000F,0x0000,
	0x0FFF,0xFF00,0x000F,0x0000,0x000F,0x0000,0x0000,0x0000,
	0x0000,0x0000,0x0000,0x0000,0x0000,0x0000,0x00FF,0x0000,
	0x00FF,0x0000,0x000F,0x0000,0x00F0,0x0000,0x0000,0x0000,
	0x0000,0x0000,0x0000,0x0000,0x0000,0x0000,0x0000,0x0000,
	0x0FFF,0xFF00,0x0000,0x0000,0x0000,0x0000,0x0000,0x0000,
	0x0000,0x0000,0x0000,0x0000,0x0000,0x0000,0x0000,0x0000,
	0x0000,0x0000,0x00FF,0x0000,0x00FF,0x0000,0x0000,0x0000,
	0x0000,0x0F00,0x0000,0xFF00,0x000F,0xF000,0x00FF,0x0000,
	0x0FF0,0x0000,0xFF00,0x0000,0xF000,0x0000,0x0000,0x0000,
	0x0FFF,0xFF00,0xFF00,0x0FF0,0xFF00,0xFFF0,0xFF0F,0x0FF0,
	0xFFF0,0x0FF0,0xFF00,0x0FF0,0x0FFF,0xFF00,0x0000,0x0000,
	0xFFFF,0xF000,0x00FF,0xF000,0x00FF,0xF000,0x00FF,0xF000,
	0x00FF,0xF000,0x00FF,0xF000,0xFFFF,0xFFF0,0x0000,0x0000,
	0x0FFF,0xFF00,0xFF00,0x0FF0,0x0000,0xFF00,0x00FF,0xF000,
	0x0FF0,0x0000,0xFF00,0x0000,0xFFFF,0xFFF0,0x0000,0x0000,
	0x0FFF,0xFF00,0xFF00,0x0FF0,0x0000,0x0FF0,0x00FF,0xFF00,
	0x0000,0x0FF0,0xFF00,0x0FF0,0x0FFF,0xFF00,0x0000,0x0000,
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
};

const __prog__ unsigned char __attribute__((space(prog))) character_conversion[256] = 
//const unsigned char character_conversion[256] =
{
  	0x00,0x16,0x0C,0x0E,0x1E,0x1C,0x1D,0x15,
	0x00,0x18,0x07,0x0F,0x1F,0x09,0x60,0x00,
	0x00,0x00,0x00,0x00,0x00,0x71,0x31,0x00,
	0x00,0x00,0x7A,0x73,0x61,0x77,0x32,0x00,
	0x00,0x63,0x78,0x64,0x65,0x34,0x33,0x00,
	0x00,0x20,0x76,0x66,0x74,0x72,0x35,0x00,
	0x00,0x6E,0x62,0x68,0x67,0x79,0x36,0x00,
	0x00,0x00,0x6D,0x6A,0x75,0x37,0x38,0x00,
	0x00,0x2C,0x6B,0x69,0x6F,0x30,0x39,0x00,
	0x00,0x2E,0x2F,0x6C,0x3B,0x70,0x2D,0x00,
	0x00,0x00,0x27,0x00,0x5B,0x3D,0x00,0x00,
	0x00,0x00,0x0D,0x5D,0x00,0x5C,0x00,0x00,
	0x00,0x00,0x00,0x00,0x00,0x00,0x08,0x00,
	0x00,0x31,0x00,0x34,0x37,0x00,0x00,0x00,
	0x30,0x2E,0x32,0x35,0x36,0x38,0x1B,0x00,
	0x19,0x2B,0x33,0x2D,0x2A,0x39,0x00,0x00,

	0x00,0x16,0x0C,0x0E,0x1E,0x1C,0x1D,0x15,
	0x00,0x18,0x07,0x0F,0x1F,0x09,0x7E,0x00,
	0x00,0x00,0x00,0x00,0x00,0x51,0x21,0x00,
	0x00,0x00,0x5A,0x53,0x41,0x57,0x40,0x00,
	0x00,0x43,0x58,0x44,0x45,0x24,0x23,0x00,
	0x00,0x20,0x56,0x46,0x54,0x52,0x25,0x00,
	0x00,0x4E,0x42,0x48,0x47,0x59,0x5E,0x00,
	0x00,0x00,0x4D,0x4A,0x55,0x26,0x2A,0x00,
	0x00,0x3C,0x4B,0x49,0x4F,0x29,0x28,0x00,
	0x00,0x3E,0x3F,0x4C,0x3A,0x50,0x5F,0x00,
	0x00,0x00,0x22,0x00,0x7B,0x2B,0x00,0x00,
	0x00,0x00,0x0D,0x7D,0x00,0x7C,0x00,0x00,
	0x00,0x00,0x00,0x00,0x00,0x00,0x08,0x00,
	0x00,0x03,0x00,0x13,0x02,0x00,0x00,0x00,
	0x1A,0x7F,0x12,0x35,0x14,0x11,0x1B,0x00,
	0x19,0x2B,0x04,0x2D,0x2A,0x01,0x00,0x00
};


void character(unsigned int x, unsigned int y, unsigned char value)
{
	unsigned int pos = (unsigned int)(value - 32) * 16;
	unsigned int pixels = 0x0000;
	unsigned char grabbed = 0x00;
  
	for (unsigned int i=y; i<y+8; i++)
	{		
		screen[i * 80 + x] = character_bitmap[pos];		
		screen[i * 80 + x + 1] = character_bitmap[pos+1];
		
		pos += 2;
	}
};

void hex(unsigned char x, unsigned char y, unsigned char value)
{
	volatile unsigned char temp = (unsigned char)((value & 0xF0) >> 4);
		
	if (temp < 0x0A) character(x, y, (unsigned char)(temp + '0'));
	else character(x, y, (unsigned char)(temp - 0x0A + 'A'));
		
	temp = (unsigned char)(value & 0x0F);
		
	if (temp < 0x0A) character(x + 0x02, y, (unsigned char)(temp + '0'));
	else character(x + 0x02, y, (unsigned char)(temp - 0x0A + 'A'));
};

void decimal(unsigned char x, unsigned char y, unsigned int value)
{
	volatile unsigned int temp = 0;
	volatile unsigned int next = 0;
	
	next = value;
	
	temp = next / 10000;
	character(x, y, (unsigned char)(temp + '0'));
	next = next - 10000 * temp;
	
	temp = next / 1000;
	character(x + 0x02, y, (unsigned char)(temp + '0'));
	next = next - 1000 * temp;
	
	temp = next / 100;
	character(x + 0x04, y, (unsigned char)(temp + '0'));
	next = next - 100 * temp;
	
	temp = next / 10;
	character(x + 0x06, y, (unsigned char)(temp + '0'));
	next = next - 10 * temp;
	
	temp = next;
	character(x + 0x08, y, (unsigned char)(temp + '0'));
};

void string(unsigned char x, unsigned char y, char *value)
{
	volatile unsigned char pos = 0;
	
	while (value[pos] != '\\')
	{
		character(x + pos * 2, y, value[pos]);
		
		pos++;
	}
};

void sound_high(unsigned int value, unsigned int duration)
{
	PR4 = value;
	line[92] = duration;
	line[90] = 0;
	T4CONbits.TON = 1;
}

void sound_low(unsigned int value, unsigned int duration)
{
	PR5 = value;
	line[93] = duration;
	line[91] = 0;
	T5CONbits.TON = 1;
}
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
